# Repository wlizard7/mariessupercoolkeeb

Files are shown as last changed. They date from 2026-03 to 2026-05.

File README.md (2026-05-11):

# mariessupercoolkeeb

This is my own personally designed keyboard, mariessupercoolkeeb! It's a keyboard with LED underlighting for each key, 70 keys (woah thats a lot), 2 encoders, and an oled screen. The microcontroller is a raspberry pi pico. I made this because I'm a laptop warrior and want an actual keyboard to plug into my laptop, maybe I'll finally get better at Valorant! (no its a skill issue)

# PCB 





This is the PCB I designed for this keyboard. I added a silkscreen on the back of my favorite character, Iroha from Cosmic Princess Kaguya, on the back to make it feel more like me! The hardest part for me was probably routing... It took me far too long. 

# FIRMWARE

The firmware was made with QMK. I don't know all much about coding but I was able to reverse engineer it using the code from the macro board I made before. 

# Case

I made the case in Fusion360! I'd like to say I'm semi well versed with CAD so it wasn't all that difficult besides the plate which took me a while.




# Final Product



# BOM

| Product | Quantity | Source | Price($) | Link |
| :-----: | :-----: | :-----: | :-----: |  :-----: |
| 3D Printed Case | - | School Printer | - | - |
| Key Stabilizers | 5 | AliExpress | $5.19 | https://a.aliexpress.com/_mPFUoOH |
| Keycaps | 1 | AliExpress | $8.17 | https://a.aliexpress.com/_mLLmu53 |
| Switches | 70 | TikTok Shop | $20.00 | https://www.tiktok.com/t/ZP98jg52vnE6u-AkbOb/ |
| PCB | 1 | JLCPCB | $23.60 | - |
| 1N4148 Diodes | 72 | AliExpress | $23.60 | https://a.aliexpress.com/_mM0KaXP |
| EC11 Rotary Encoder | 1 | AliExpress | $1.58 | https://a.aliexpress.com/_mOKYpCH |
| 0.91 inch OLED display | 1 | AliExpress |$2.37 | https://a.aliexpress.com/_mNspyVF |
| Raspberry Pi Pico | 1 | AliExpress |$3.96| https://a.aliexpress.com/_m0asVHP |
| SK6812 MINI-E | 70 | AliExpress |$3.50 | https://a.aliexpress.com/_m0NRr4N |
| M3 Threaded Inserts | 12 | Have Already | - | - |
| M3 Screws | 12 | Have Already | - | - |

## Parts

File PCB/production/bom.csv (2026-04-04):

Designator | Footprint | Quantity | Value | LCSC Part #
A1 | RaspberryPi_Pico_Common_Unspecified | 1 | RaspberryPi_Pico
D1, D10, D11, D12, D13, D14, D15, D16, D17, D18, D19, D2, D20, D21, D22, D23, D24, D25, D26, D27, D28, D29, D3, D30, D31, D32, D33, D34, D35, D36, D37, D38, D39, D4, D40, D41, D42, D43, D44, D45, D46, D47, D48, D49, D5, D50, D51, D52, D53, D54, D55, D56, D57, D58, D59, D6, D60, D61, D62, D63, D64, D65, D66, D67, D68, D69, D7, D70, D71, D72, D8, D9 | D_DO-35_SOD27_P7.62mm_Horizontal | 72 | D_Small
D100, D101, D102, D103, D104, D105, D106, D107, D108, D109, D110, D111, D112, D113, D114, D115, D116, D117, D118, D119, D120, D121, D122, D123, D124, D125, D126, D127, D128, D129, D130, D131, D132, D133, D134, D135, D136, D137, D138, D139, D140, D141, D142, D73, D74, D75, D76, D77, D78, D79, D80, D81, D82, D83, D84, D85, D86, D87, D88, D89, D90, D91, D92, D93, D94, D95, D96, D97, D98, D99 | MX_SK6812MINI-E_REV | 70 | SK6812MINI-E
MSW1, MSW2, MSW3, MSW4, MSW5, MSW6, MSW7, MSW8, SW1, SW10, SW11, SW12, SW13, SW16, SW17, SW18, SW19, SW2, SW20, SW21, SW22, SW23, SW24, SW25, SW26, SW27, SW3, SW30, SW31, SW32, SW33, SW34, SW35, SW36, SW37, SW38, SW39, SW4, SW40, SW44, SW45, SW46, SW47, SW48, SW49, SW5, SW50, SW51, SW52, SW53, SW6, SW7, SW8, SW9 | SW_Cherry_MX_1.00u_PCB | 54 | SW_Push
SW14 | SW_Cherry_MX_2.00u_PCB | 1 | SW_Push
SW15, SW28 | SW_Cherry_MX_1.50u_PCB | 2 | SW_Push
SW29 | SW_Cherry_MX_1.75u_PCB | 1 | SW_Push
SW41, SW43 | SW_Cherry_MX_2.25u_PCB | 2 | SW_Push
SW42 | SW_Cherry_MX_2.75u_PCB | 1 | SW_Push
SW54, SW55, SW56, SW58, SW59, SW60, SW61, SW62 | SW_Cherry_MX_1.25u_PCB | 8 | SW_Push
SW57 | SW_Cherry_MX_6.25u_PCB | 1 | SW_Push
SW63, SW85 | RotaryEncoder_Alps_EC11E-Switch_Vertical_H20mm | 2 | RotaryEncoder_Switch
U1 | OLED_0.91_128x32 | 1 | OLED_0.91_128x32

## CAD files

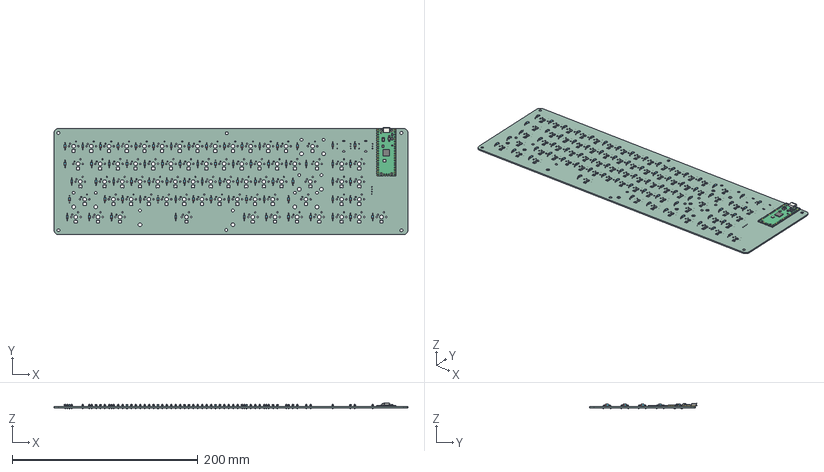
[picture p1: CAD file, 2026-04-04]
PCB/mariekeeb.step
381.0 x 115.6 x 6.20 mm
D_DO-35_SOD27_P7.62mm_Horizontal x 72
RaspberryPi_Pico_Module_KiCad
mariekeeb_PCB

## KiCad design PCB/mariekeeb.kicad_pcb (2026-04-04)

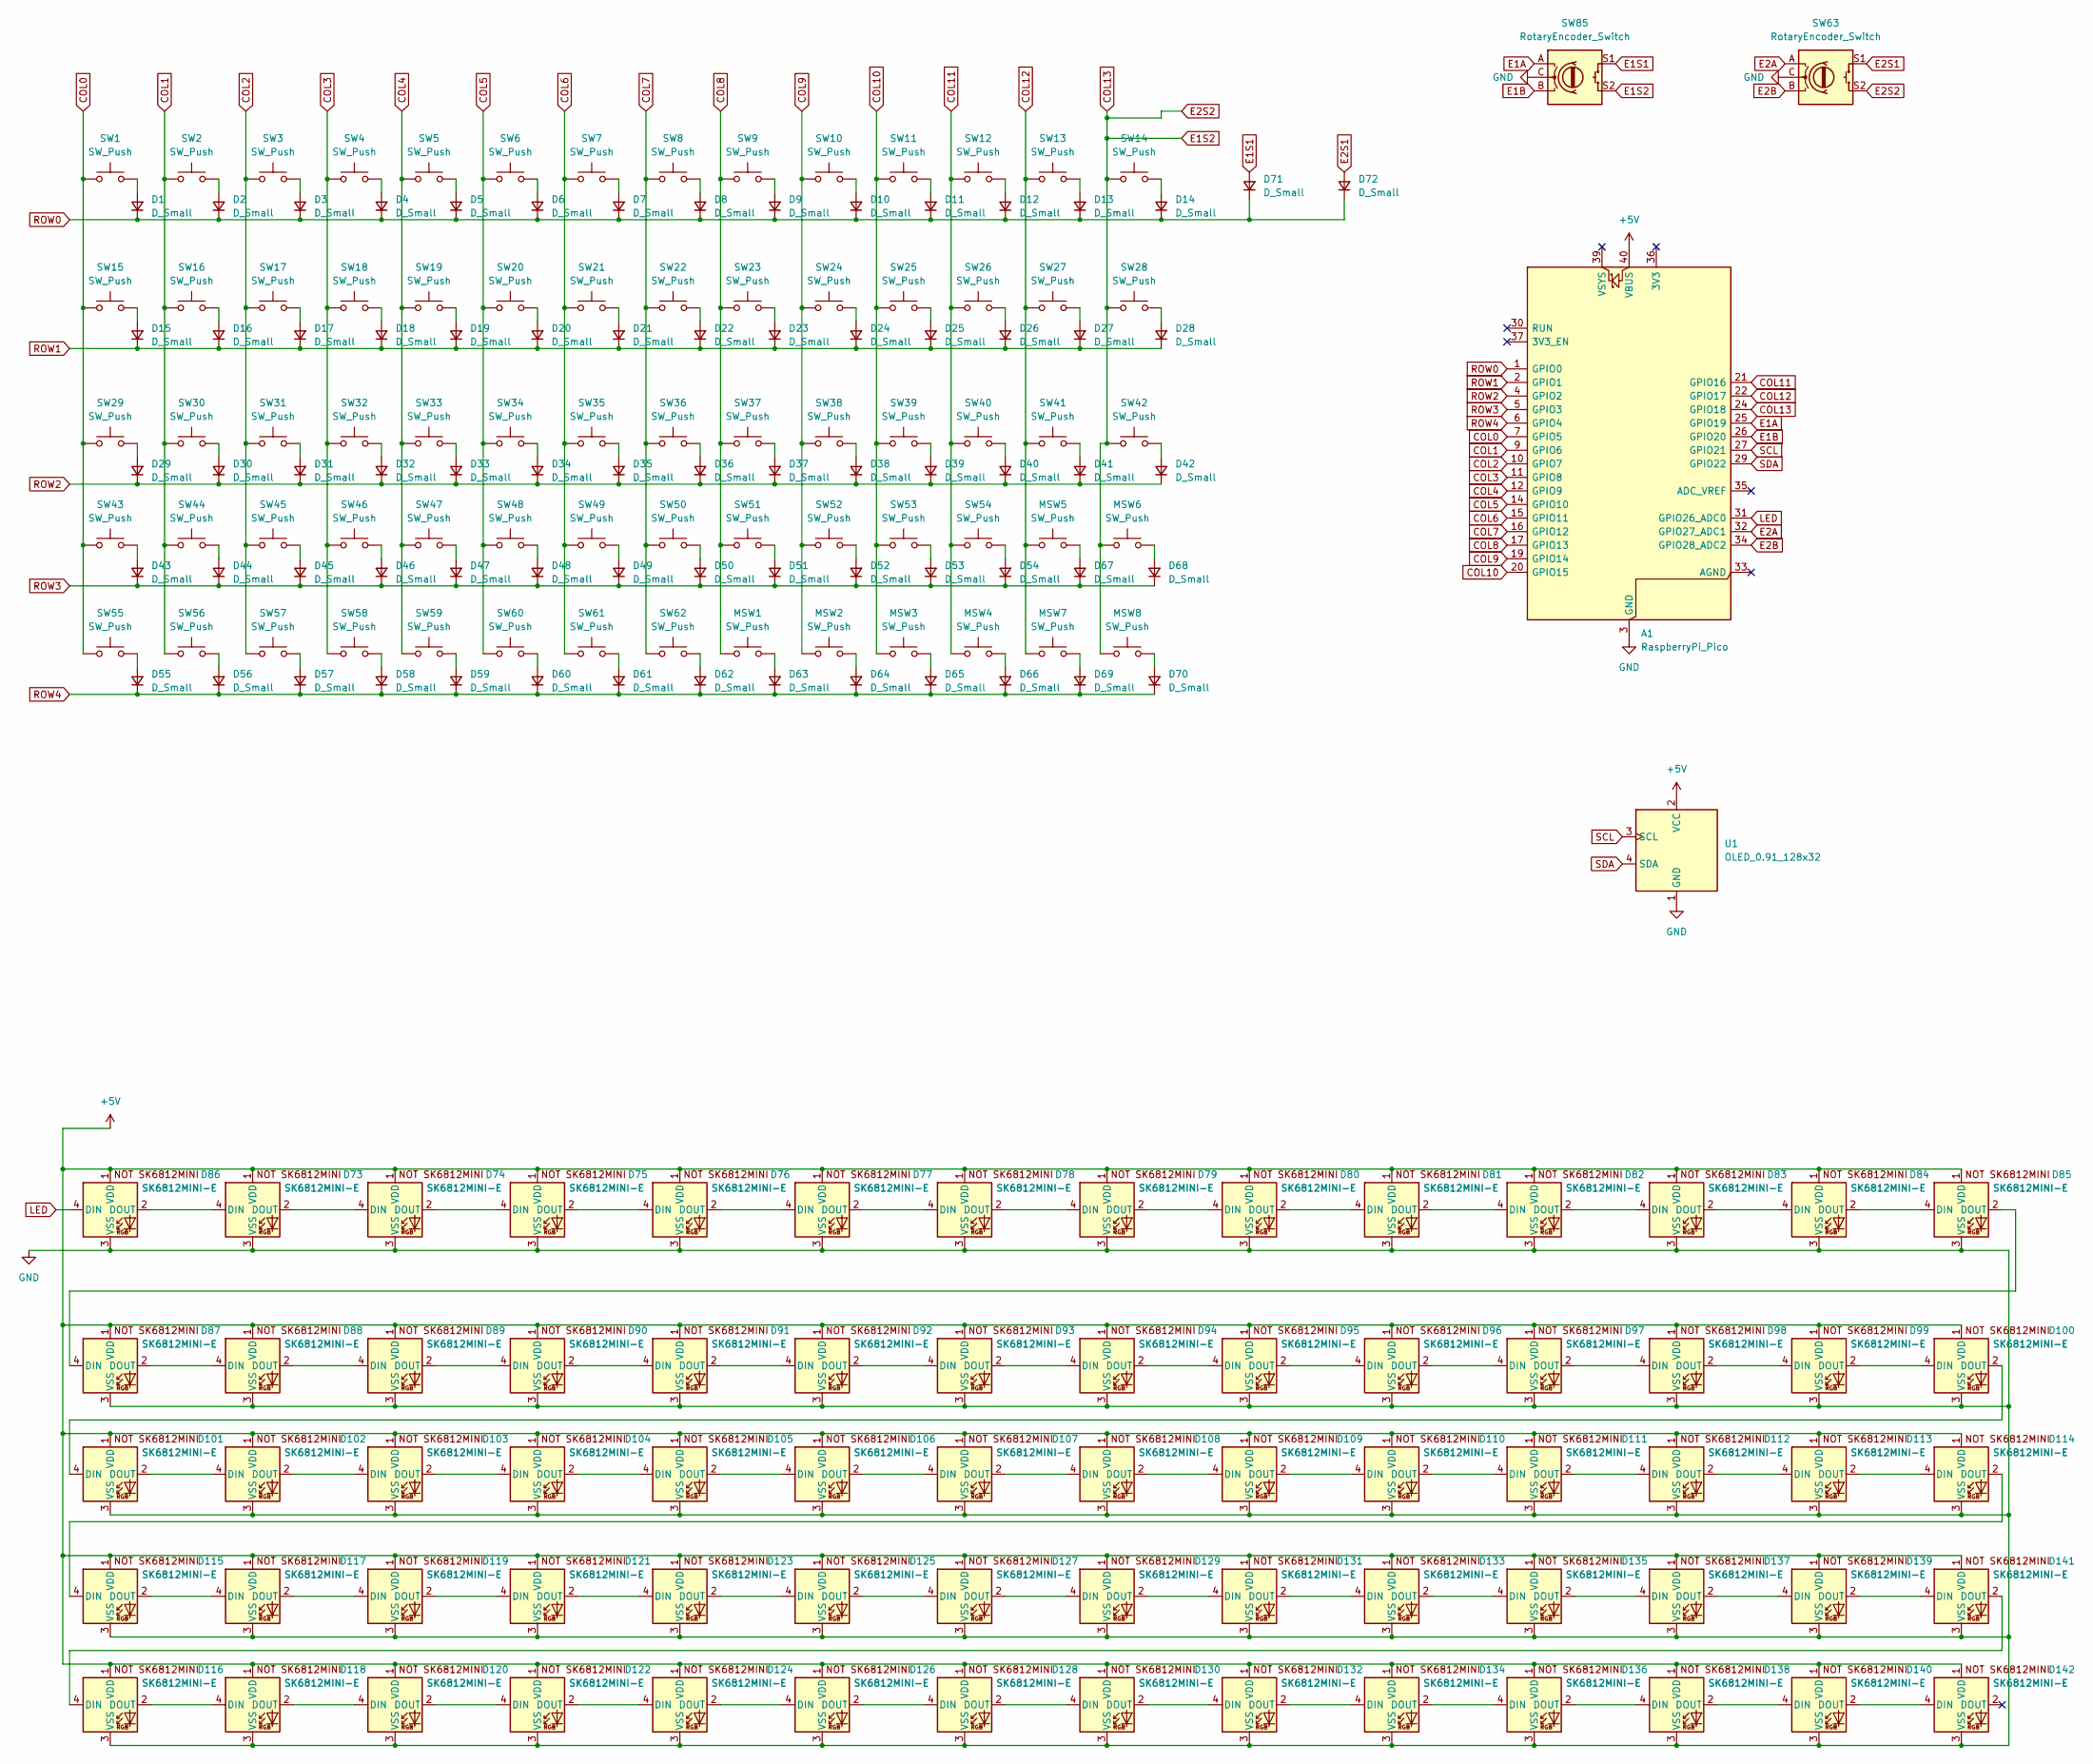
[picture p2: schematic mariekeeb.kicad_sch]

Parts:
A1: RaspberryPi_Pico; RaspberryPi_Pico_Common_Unspecified
D1, D2, D3, D4, D5, D6, D7, D8, D9, D10, D11, D12, D13, D14, D15, D16, D17, D18, D19, D20, D21, D22, D23, D24, D25, D26, D27, D28, D29, D30, D31, D32, D33, D34, D35, D36, D37, D38, D39, D40, D41, D42, D43, D44, D45, D46, D47, D48, D49, D50, D51, D52, D53, D54, D55, D56, D57, D58, D59, D60, D61, D62, D63, D64, D65, D66, D67, D68, D69, D70, D71, D72: D_Small; D_DO-35_SOD27_P7.62mm_Horizontal
D73, D74, D75, D76, D77, D78, D79, D80, D81, D82, D83, D84, D85, D86, D87, D88, D89, D90, D91, D92, D93, D94, D95, D96, D97, D98, D99, D100, D101, D102, D103, D104, D105, D106, D107, D108, D109, D110, D111, D112, D113, D114, D115, D116, D117, D118, D119, D120, D121, D122, D123, D124, D125, D126, D127, D128, D129, D130, D131, D132, D133, D134, D135, D136, D137, D138, D139, D140, D141, D142: SK6812MINI-E; MX_SK6812MINI-E_REV
MSW1, MSW2, MSW3, MSW4, MSW5, MSW6, MSW7, MSW8: SW_Push; SW_Cherry_MX_1.00u_PCB
SW1, SW2, SW3, SW4, SW5, SW6, SW7, SW8, SW9, SW10, SW11, SW12, SW13, SW16, SW17, SW18, SW19, SW20, SW21, SW22, SW23, SW24, SW25, SW26, SW27, SW30, SW31, SW32, SW33, SW34, SW35, SW36, SW37, SW38, SW39, SW40, SW44, SW45, SW46, SW47, SW48, SW49, SW50, SW51, SW52, SW53: SW_Push; SW_Cherry_MX_1.00u_PCB
SW14: SW_Push; SW_Cherry_MX_2.00u_PCB
SW15, SW28: SW_Push; SW_Cherry_MX_1.50u_PCB
SW29: SW_Push; SW_Cherry_MX_1.75u_PCB
SW41, SW43: SW_Push; SW_Cherry_MX_2.25u_PCB
SW42: SW_Push; SW_Cherry_MX_2.75u_PCB
SW54, SW55, SW56, SW58, SW59, SW60, SW61, SW62: SW_Push; SW_Cherry_MX_1.25u_PCB
SW57: SW_Push; SW_Cherry_MX_6.25u_PCB
SW63, SW85: RotaryEncoder_Switch; RotaryEncoder_Alps_EC11E-Switch_Vertical_H20mm
U1: OLED_0.91_128x32

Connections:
+5V: A1.40 (VBUS), D73.1 (VDD), D74.1 (VDD), D75.1 (VDD), D76.1 (VDD), D77.1 (VDD), D78.1 (VDD), D79.1 (VDD), D80.1 (VDD), D81.1 (VDD), D82.1 (VDD), D83.1 (VDD), D84.1 (VDD), D85.1 (VDD), D86.1 (VDD), D87.1 (VDD), D88.1 (VDD), D89.1 (VDD), D90.1 (VDD), D91.1 (VDD), D92.1 (VDD), D93.1 (VDD), D94.1 (VDD), D95.1 (VDD), D96.1 (VDD), D97.1 (VDD), D98.1 (VDD), D99.1 (VDD), D100.1 (VDD), D101.1 (VDD), D102.1 (VDD), D103.1 (VDD), D104.1 (VDD), D105.1 (VDD), D106.1 (VDD), D107.1 (VDD), D108.1 (VDD), D109.1 (VDD), D110.1 (VDD), D111.1 (VDD), D112.1 (VDD), D113.1 (VDD), D114.1 (VDD), D115.1 (VDD), D116.1 (VDD), D117.1 (VDD), D118.1 (VDD), D119.1 (VDD), D120.1 (VDD), D121.1 (VDD), D122.1 (VDD), D123.1 (VDD), D124.1 (VDD), D125.1 (VDD), D126.1 (VDD), D127.1 (VDD), D128.1 (VDD), D129.1 (VDD), D130.1 (VDD), D131.1 (VDD), D132.1 (VDD), D133.1 (VDD), D134.1 (VDD), D135.1 (VDD), D136.1 (VDD), D137.1 (VDD), D138.1 (VDD), D139.1 (VDD), D140.1 (VDD), D141.1 (VDD), D142.1 (VDD), U1.2 (VCC)
COL0: A1.7 (GPIO5), SW1.1, SW15.1, SW29.1, SW43.1, SW55.1
COL1: A1.9 (GPIO6), SW2.1, SW16.1, SW30.1, SW44.1, SW56.1
COL2: A1.10 (GPIO7), SW3.1, SW17.1, SW31.1, SW45.1, SW57.1
COL3: A1.11 (GPIO8), SW4.1, SW18.1, SW32.1, SW46.1, SW58.1
COL4: A1.12 (GPIO9), SW5.1, SW19.1, SW33.1, SW47.1, SW59.1
COL5: A1.14 (GPIO10), SW6.1, SW20.1, SW34.1, SW48.1, SW60.1
COL6: A1.15 (GPIO11), SW7.1, SW21.1, SW35.1, SW49.1, SW61.1
COL7: A1.16 (GPIO12), SW8.1, SW22.1, SW36.1, SW50.1, SW62.1
COL8: A1.17 (GPIO13), MSW1.1, SW9.1, SW23.1, SW37.1, SW51.1
COL9: A1.19 (GPIO14), MSW2.1, SW10.1, SW24.1, SW38.1, SW52.1
COL10: A1.20 (GPIO15), MSW3.1, SW11.1, SW25.1, SW39.1, SW53.1
COL11: A1.21 (GPIO16), MSW4.1, SW12.1, SW26.1, SW40.1, SW54.1
COL12: A1.22 (GPIO17), MSW5.1, MSW7.1, SW13.1, SW27.1, SW41.1
COL13: A1.24 (GPIO18), MSW6.1, MSW8.1, SW14.1, SW28.1, SW42.1, SW63.S2, SW85.S2
E1A: A1.25 (GPIO19), SW85.A
E1B: A1.26 (GPIO20), SW85.B
E1S1: D71.2 (A), SW85.S1
E2A: A1.32 (GPIO27_ADC1), SW63.A
E2B: A1.34 (GPIO28_ADC2), SW63.B
E2S1: D72.2 (A), SW63.S1
GND: A1.3 (GND), A1.8 (GND), A1.13 (GND), A1.18 (GND), A1.23 (GND), A1.28 (GND), A1.38 (GND), D73.3 (VSS), D74.3 (VSS), D75.3 (VSS), D76.3 (VSS), D77.3 (VSS), D78.3 (VSS), D79.3 (VSS), D80.3 (VSS), D81.3 (VSS), D82.3 (VSS), D83.3 (VSS), D84.3 (VSS), D85.3 (VSS), D86.3 (VSS), D87.3 (VSS), D88.3 (VSS), D89.3 (VSS), D90.3 (VSS), D91.3 (VSS), D92.3 (VSS), D93.3 (VSS), D94.3 (VSS), D95.3 (VSS), D96.3 (VSS), D97.3 (VSS), D98.3 (VSS), D99.3 (VSS), D100.3 (VSS), D101.3 (VSS), D102.3 (VSS), D103.3 (VSS), D104.3 (VSS), D105.3 (VSS), D106.3 (VSS), D107.3 (VSS), D108.3 (VSS), D109.3 (VSS), D110.3 (VSS), D111.3 (VSS), D112.3 (VSS), D113.3 (VSS), D114.3 (VSS), D115.3 (VSS), D116.3 (VSS), D117.3 (VSS), D118.3 (VSS), D119.3 (VSS), D120.3 (VSS), D121.3 (VSS), D122.3 (VSS), D123.3 (VSS), D124.3 (VSS), D125.3 (VSS), D126.3 (VSS), D127.3 (VSS), D128.3 (VSS), D129.3 (VSS), D130.3 (VSS), D131.3 (VSS), D132.3 (VSS), D133.3 (VSS), D134.3 (VSS), D135.3 (VSS), D136.3 (VSS), D137.3 (VSS), D138.3 (VSS), D139.3 (VSS), D140.3 (VSS), D141.3 (VSS), D142.3 (VSS), SW63.C, SW85.C, U1.1 (GND)
LED: A1.31 (GPIO26_ADC0), D86.4 (DIN)
unnamed: D1.2 (A), SW1.2
unnamed: D2.2 (A), SW2.2
unnamed: D3.2 (A), SW3.2
unnamed: D4.2 (A), SW4.2
unnamed: D5.2 (A), SW5.2
unnamed: D6.2 (A), SW6.2
unnamed: D7.2 (A), SW7.2
unnamed: D8.2 (A), SW8.2
unnamed: D9.2 (A), SW9.2
unnamed: D10.2 (A), SW10.2
unnamed: D11.2 (A), SW11.2
unnamed: D12.2 (A), SW12.2
unnamed: D13.2 (A), SW13.2
unnamed: D14.2 (A), SW14.2
unnamed: D15.2 (A), SW15.2
unnamed: D16.2 (A), SW16.2
unnamed: D17.2 (A), SW17.2
unnamed: D18.2 (A), SW18.2
unnamed: D19.2 (A), SW19.2
unnamed: D20.2 (A), SW20.2
unnamed: D21.2 (A), SW21.2
unnamed: D22.2 (A), SW22.2
unnamed: D23.2 (A), SW23.2
unnamed: D24.2 (A), SW24.2
unnamed: D25.2 (A), SW25.2
unnamed: D26.2 (A), SW26.2
unnamed: D27.2 (A), SW27.2
unnamed: D28.2 (A), SW28.2
unnamed: D29.2 (A), SW29.2
unnamed: D30.2 (A), SW30.2
unnamed: D31.2 (A), SW31.2
unnamed: D32.2 (A), SW32.2
unnamed: D33.2 (A), SW33.2
unnamed: D34.2 (A), SW34.2
unnamed: D35.2 (A), SW35.2
unnamed: D36.2 (A), SW36.2
unnamed: D37.2 (A), SW37.2
unnamed: D38.2 (A), SW38.2
unnamed: D39.2 (A), SW39.2
unnamed: D40.2 (A), SW40.2
unnamed: D41.2 (A), SW41.2
unnamed: D42.2 (A), SW42.2
unnamed: D43.2 (A), SW43.2
unnamed: D44.2 (A), SW44.2
unnamed: D45.2 (A), SW45.2
unnamed: D46.2 (A), SW46.2
unnamed: D47.2 (A), SW47.2
unnamed: D48.2 (A), SW48.2
unnamed: D49.2 (A), SW49.2
unnamed: D50.2 (A), SW50.2
unnamed: D51.2 (A), SW51.2
unnamed: D52.2 (A), SW52.2
unnamed: D53.2 (A), SW53.2
unnamed: D54.2 (A), SW54.2
unnamed: D55.2 (A), SW55.2
unnamed: D56.2 (A), SW56.2
unnamed: D57.2 (A), SW57.2
unnamed: D58.2 (A), SW58.2
unnamed: D59.2 (A), SW59.2
unnamed: D60.2 (A), SW60.2
unnamed: D61.2 (A), SW61.2
unnamed: D62.2 (A), SW62.2
unnamed: D63.2 (A), MSW1.2
unnamed: D64.2 (A), MSW2.2
unnamed: D65.2 (A), MSW3.2
unnamed: D66.2 (A), MSW4.2
unnamed: D67.2 (A), MSW5.2
unnamed: D68.2 (A), MSW6.2
unnamed: D69.2 (A), MSW7.2
unnamed: D70.2 (A), MSW8.2
unnamed: D73.4 (DIN), D86.2 (DOUT)
unnamed: D73.2 (DOUT), D74.4 (DIN)
unnamed: D74.2 (DOUT), D75.4 (DIN)
unnamed: D75.2 (DOUT), D76.4 (DIN)
unnamed: D76.2 (DOUT), D77.4 (DIN)
unnamed: D77.2 (DOUT), D78.4 (DIN)
unnamed: D78.2 (DOUT), D79.4 (DIN)
unnamed: D79.2 (DOUT), D80.4 (DIN)
unnamed: D80.2 (DOUT), D81.4 (DIN)
unnamed: D81.2 (DOUT), D82.4 (DIN)
unnamed: D82.2 (DOUT), D83.4 (DIN)
unnamed: D83.2 (DOUT), D84.4 (DIN)
unnamed: D84.2 (DOUT), D85.4 (DIN)
unnamed: D85.2 (DOUT), D87.4 (DIN)
unnamed: D87.2 (DOUT), D88.4 (DIN)
unnamed: D88.2 (DOUT), D89.4 (DIN)
unnamed: D89.2 (DOUT), D90.4 (DIN)
unnamed: D90.2 (DOUT), D91.4 (DIN)
unnamed: D91.2 (DOUT), D92.4 (DIN)
unnamed: D92.2 (DOUT), D93.4 (DIN)
unnamed: D93.2 (DOUT), D94.4 (DIN)
unnamed: D94.2 (DOUT), D95.4 (DIN)
unnamed: D95.2 (DOUT), D96.4 (DIN)
unnamed: D96.2 (DOUT), D97.4 (DIN)
unnamed: D97.2 (DOUT), D98.4 (DIN)
unnamed: D98.2 (DOUT), D99.4 (DIN)
unnamed: D99.2 (DOUT), D100.4 (DIN)
unnamed: D100.2 (DOUT), D101.4 (DIN)
unnamed: D101.2 (DOUT), D102.4 (DIN)
unnamed: D102.2 (DOUT), D103.4 (DIN)
unnamed: D103.2 (DOUT), D104.4 (DIN)
unnamed: D104.2 (DOUT), D105.4 (DIN)
unnamed: D105.2 (DOUT), D106.4 (DIN)
unnamed: D106.2 (DOUT), D107.4 (DIN)
unnamed: D107.2 (DOUT), D108.4 (DIN)
unnamed: D108.2 (DOUT), D109.4 (DIN)
unnamed: D109.2 (DOUT), D110.4 (DIN)
unnamed: D110.2 (DOUT), D111.4 (DIN)
unnamed: D111.2 (DOUT), D112.4 (DIN)
unnamed: D112.2 (DOUT), D113.4 (DIN)
unnamed: D113.2 (DOUT), D114.4 (DIN)
unnamed: D114.2 (DOUT), D115.4 (DIN)
unnamed: D115.2 (DOUT), D117.4 (DIN)
unnamed: D116.4 (DIN), D141.2 (DOUT)
unnamed: D116.2 (DOUT), D118.4 (DIN)
unnamed: D117.2 (DOUT), D119.4 (DIN)
unnamed: D118.2 (DOUT), D120.4 (DIN)
unnamed: D119.2 (DOUT), D121.4 (DIN)
unnamed: D120.2 (DOUT), D122.4 (DIN)
unnamed: D121.2 (DOUT), D123.4 (DIN)
unnamed: D122.2 (DOUT), D124.4 (DIN)
unnamed: D123.2 (DOUT), D125.4 (DIN)
unnamed: D124.2 (DOUT), D126.4 (DIN)
unnamed: D125.2 (DOUT), D127.4 (DIN)
unnamed: D126.2 (DOUT), D128.4 (DIN)
unnamed: D127.2 (DOUT), D129.4 (DIN)
unnamed: D128.2 (DOUT), D130.4 (DIN)
unnamed: D129.2 (DOUT), D131.4 (DIN)
unnamed: D130.2 (DOUT), D132.4 (DIN)
unnamed: D131.2 (DOUT), D133.4 (DIN)
unnamed: D132.2 (DOUT), D134.4 (DIN)
unnamed: D133.2 (DOUT), D135.4 (DIN)
unnamed: D134.2 (DOUT), D136.4 (DIN)
unnamed: D135.2 (DOUT), D137.4 (DIN)
unnamed: D136.2 (DOUT), D138.4 (DIN)
unnamed: D137.2 (DOUT), D139.4 (DIN)
unnamed: D138.2 (DOUT), D140.4 (DIN)
unnamed: D139.2 (DOUT), D141.4 (DIN)
unnamed: D140.2 (DOUT), D142.4 (DIN)
ROW0: A1.1 (GPIO0), D1.1 (K), D2.1 (K), D3.1 (K), D4.1 (K), D5.1 (K), D6.1 (K), D7.1 (K), D8.1 (K), D9.1 (K), D10.1 (K), D11.1 (K), D12.1 (K), D13.1 (K), D14.1 (K), D71.1 (K), D72.1 (K)
ROW1: A1.2 (GPIO1), D15.1 (K), D16.1 (K), D17.1 (K), D18.1 (K), D19.1 (K), D20.1 (K), D21.1 (K), D22.1 (K), D23.1 (K), D24.1 (K), D25.1 (K), D26.1 (K), D27.1 (K), D28.1 (K)
ROW2: A1.4 (GPIO2), D29.1 (K), D30.1 (K), D31.1 (K), D32.1 (K), D33.1 (K), D34.1 (K), D35.1 (K), D36.1 (K), D37.1 (K), D38.1 (K), D39.1 (K), D40.1 (K), D41.1 (K), D42.1 (K)
ROW3: A1.5 (GPIO3), D43.1 (K), D44.1 (K), D45.1 (K), D46.1 (K), D47.1 (K), D48.1 (K), D49.1 (K), D50.1 (K), D51.1 (K), D52.1 (K), D53.1 (K), D54.1 (K), D67.1 (K), D68.1 (K)
ROW4: A1.6 (GPIO4), D55.1 (K), D56.1 (K), D57.1 (K), D58.1 (K), D59.1 (K), D60.1 (K), D61.1 (K), D62.1 (K), D63.1 (K), D64.1 (K), D65.1 (K), D66.1 (K), D69.1 (K), D70.1 (K)
SCL: A1.27 (GPIO21), U1.3 (SCL)
SDA: A1.29 (GPIO22), U1.4 (SDA)

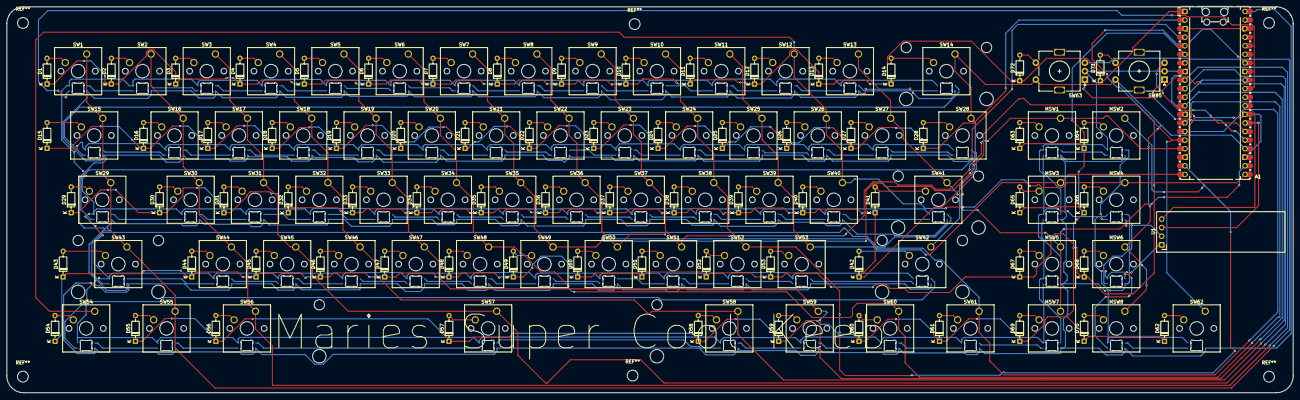
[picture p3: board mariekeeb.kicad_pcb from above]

Board: 2 copper layers, 381.0 x 114.3 mm, 216 parts (0 on the bottom side), 169 nets.

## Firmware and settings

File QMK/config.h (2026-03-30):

#pragma once

#define MATRIX_ROWS 5
#define MATRIX_COLS 14

#define ENCODERS 2
#define ENCODER_RESOLUTION 4
#define ENCODER_A_PINS { GP19, GP20 }
#define ENCODER_B_PINS { GP27, GP28 }
